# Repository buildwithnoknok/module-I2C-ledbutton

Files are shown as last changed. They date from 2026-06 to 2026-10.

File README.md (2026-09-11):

# noknok LED Button

A compact I²C‑controlled button module with integrated RGB LED backlight for the noknok ecosystem.  
Designed for user input, menu navigation, and illuminated UI feedback in modular builds.

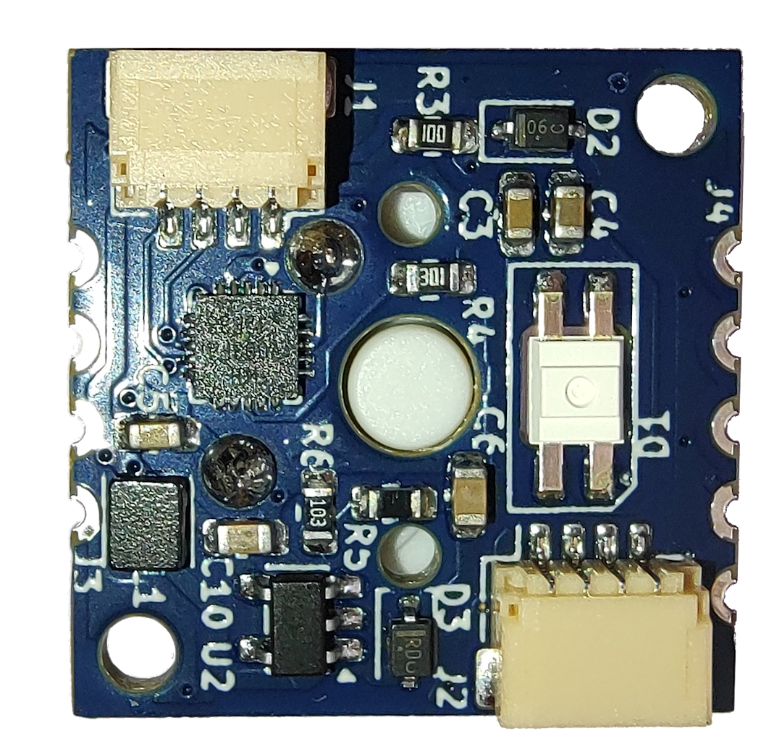
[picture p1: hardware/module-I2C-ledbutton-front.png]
LED Button Module Front

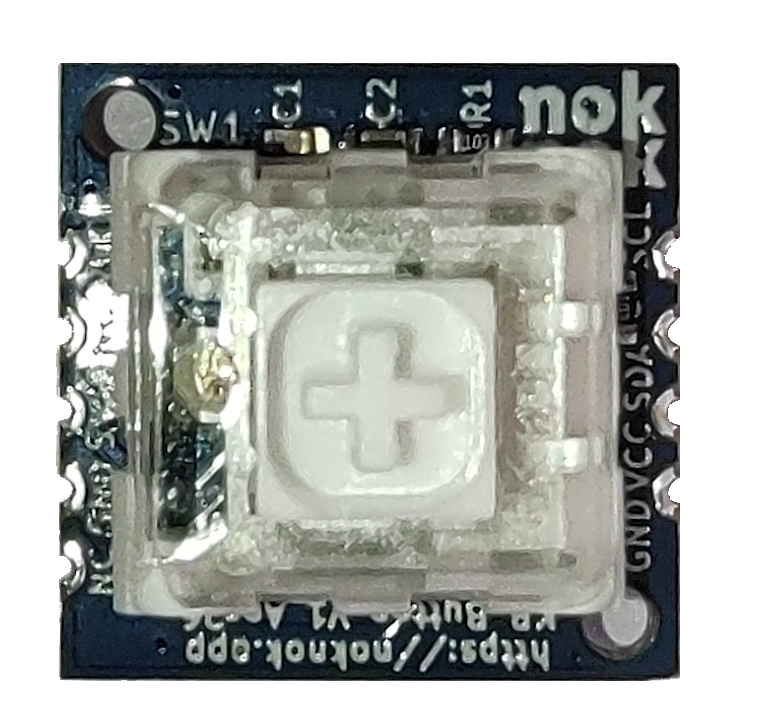
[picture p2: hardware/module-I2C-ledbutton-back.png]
LED Button Module Back


---

## Overview

The **noknok LED Button** uses a **CH32V003F4U6** microcontroller to read a tactile push button and drive an **SK6812MINI-E** RGB LED via SPI+DMA. It connects to the Raspberry Pi Pico (Conductor) over the standard noknok **JST SH 4‑pin I²C connector**.

The I²C address is assigned dynamically at boot — no conflicts when using multiple modules on the same bus.

Typical use cases:
- Menu selection (OK / Back / Cancel)
- Illuminated status indicators
- Multi‑button control panels
- Confirm actions with colour feedback

---

## Features

- Dynamic I²C address via noknok enumeration protocol (no hardcoded address)
- CH32V003F4U6 microcontroller (RISC‑V, 48 MHz, QFN-20)
- SK6812MINI-E RGB LED (SPI + DMA driven — CPU-free updates)
- Tactile push button with 20 ms hardware debounce
- Press edge, release edge, and cumulative press count — no polling gaps
- 3.3V operation via noknok I²C connector
- Compact 20×20 mm PCB

---

## I²C Protocol

**I²C address:** assigned dynamically at boot — see [Enumeration](#enumeration).

### Commands (Pico → Module)

| Bytes | Command | Description |
|---|---|---|
| `0x00` | **LED OFF** | Turn LED off immediately |
| `0x10` `R` `G` `B` `0x00` | **SET COLOR** | Set LED colour (R, G, B each 0–255) |
| `0x11` | **RESET COUNT** | Reset cumulative press counter to 0 |
| `0xB0` | **ENTER BOOTLOADER** | Reset into the I²C bootloader for an over‑the‑wire firmware update (see [Firmware](#firmware)) |
| `0xB1` | **GET VERSION** | Standard noknok command — the next read returns 4 version bytes (see below) |

### Version read (Pico ← Module)

`GET_VERSION` (`0xB1`) is a **noknok ecosystem-standard** command (the `0xB0`–`0xBF` range is reserved for standard commands across every module). Write `0xB1`, then read **4 bytes**: `[PROTOCOL_VERSION, FW_MAJOR, FW_MINOR, FW_PATCH]` = `[0x01, 2, 2, 0]`. Lets the Conductor compare the installed version against the version required by the product manifest. **→ Full spec:** [Ecosystem / software / readme.md §5](https://github.com/buildwithnoknok/Ecosystem/blob/main/software/readme.md#5-standard-system-commands)

### Status read (Pico ← Module)

Read **2 bytes**:

**Byte 0 — status flags:**

| Bit | Meaning |
|-----|---|
| 0 | Button currently pressed (`1` = held down) |
| 1 | Press event since last read (edge, auto-clears) |
| 2 | Release event since last read (edge, auto-clears) |

**Byte 1 — cumulative press count** (0–255, wraps)

> Edge flags (bits 1 and 2) are cleared on the module after each read. Poll at ~50 ms and you won't miss any press or release.

---

## Enumeration

The module uses the standard noknok dynamic enumeration protocol — no hardcoded I²C address. At boot it flashes the LED white briefly, then counts a UID-derived backoff delay before joining the bus at `0x7F` for address assignment. On successful assignment, the LED flashes green.

**→ Full protocol spec:** [Ecosystem / software / enumeration.md](https://github.com/buildwithnoknok/Ecosystem/blob/main/software/enumeration.md)

---

## Python API

Use the `noknok.py` library from the [Ecosystem repo](https://github.com/buildwithnoknok/Ecosystem/tree/main/software/pico) on the Pico.

```python
from noknok import Conductor

c = Conductor()        # GP8 = SDA, GP9 = SCL
c.enumerate()          # discover all modules (~3 s)

kb = c.ledbutton[0]             # first LED Button by discovery order
# or: kb = c.role["ok_button"]  # by role name after setup_roles()

# LED control
kb.set_color(255, 0, 0)         # red
kb.set_color(0, 255, 0)         # green
kb.set_color(255, 255, 255)     # white
kb.led_off()

# Button reading — returns LedButtonStatus or None on I2C error
s = kb.read()
if s is not None:
    print(s.pressed)        # True if held right now
    print(s.press_event)    # True if pressed since last read
    print(s.release_event)  # True if released since last read
    print(s.count)          # cumulative press count (0–255)

# Reset counter
kb.reset_count()
```

---

## Hardware

| Spec | Value |
|---|---|
| PCB size | 20 × 20 mm |
| MCU | CH32V003F4U6 (QFN‑20, RISC‑V, 48 MHz) |
| LED | SK6812MINI-E (RGB, SPI-driven) |
| Button | Tactile switch, active LOW, internal pull-up |
| Connector | JST SH 4‑pin (Qwiic / STEMMA QT compatible) |
| Supply voltage | 3.3V via I²C connector |
| LED data pin | PC6 (SPI1 MOSI, DMA-driven) |
| Button pin | PD4 (active LOW) |
| I²C SDA | PC1 |
| I²C SCL | PC2 |
| Flash header | J3 — 3-pad pogo (GND, SWIO, VCC), noknok M2.5-keyed footprint. SWIO/PD1 also carries the status LED (D4, active LOW). |
| Hardware version | v2.0 |

---

## Firmware

**v2.4 runs under the shared noknok I²C bootloader** ([module-I2C-bootloader](https://github.com/buildwithnoknok/module-I2C-bootloader)), so the module can be re‑flashed **over the I²C bus** — no SWDIO cable needed in the field.

Flash map (16 KB):

| Region | Address | Written by |
|---|---|---|
| Bootloader — stage-0 (1 KB, frozen) + stage-1 (4 KB, OTA-updatable) | `0x0000` | SWD, **once** at manufacture |
| Application (this firmware) | `0x1400` | I²C OTA |
| Metadata (validity marker) | `0x3FC0` | I²C OTA |

The application is linked at the `0x1400` offset (`app.ld`, bootloader layout 2) and reserves the top 16 bytes of RAM for the bootloader handoff cell. Command `0xB0` drops the running module back into the bootloader for an update.

### Build

```bash
cd firmware/src
make build   # compile the offset-linked application -> keyboard_firmware.bin
```

> ch32fun must be installed at `../ch32fun/` relative to `firmware/src/` — see [cnlohr/ch32v003fun](https://github.com/cnlohr/ch32v003fun) for setup.

### Flashing

- **Normal (over I²C):** flash `keyboard_firmware.bin` from the Pico using the noknok flasher (`module_flasher.py` in `brain-Pico`). No cable.
- **First time / blank board:** SWD‑flash the bootloader once (`make flash` in the bootloader repo), then flash this app over I²C.
- **Backup / recovery (SWD):** the 5‑pin SWIO header is the unbrickable backstop — see *Recovery & SWD flashing* in the [bootloader README](https://github.com/buildwithnoknok/module-I2C-bootloader#recovery--swd-flashing).

`make flash` here still does a one‑off SWD flash of the app for bench bring‑up if you need it.

| Metric | Value |
|---|---|
| Firmware version | v2.4.1 (bootloader‑hosted, app base `0x1400`) |
| Application size | 3144 B (of the 10 KB app region) |

---

## Changelog

### Hardware v2.0 — status LED, pogo flash pads, no on-board pull-ups
Status LED on PD1/SWIO, castellated edges replaced with 3-pad pogo flashing pads (J3), on-board I²C pull-ups removed (host-only now). Full change record: [hardware/readme.md](hardware/readme.md#hardware-change-record).

### v2.4.1 — version bump only (firmware-index bring-up)
No functional change. Cut purely to give the new firmware-index OTA path a real installed-vs-current delta to exercise end to end (resolve → bootloader gate → fetch → flash → verify). Identical to v2.4.0 apart from the `GET_VERSION` patch byte. Ships alongside the first [`firmware/index.json`](firmware/index.json), which is how the brain now discovers the current firmware for this module — see [Ecosystem / software / firmware-index.md](https://github.com/buildwithnoknok/Ecosystem/blob/main/software/firmware-index.md).

### v2.4.0 — app base 0x1400 (bootloader layout 2)
Relinked at the `0x1400` flash offset (bootloader **layout 2**: 1 KB stage-0 + 4 KB stage-1 below the app; was `0x1000`). Firmware behaviour unchanged. **Not compatible with the legacy monolithic bootloader or a layout-1 stage-1** — such a module gets stage-0 + stage-1 v1.1.0 over SWD first, then this app over I²C. See [module-I2C-bootloader](https://github.com/buildwithnoknok/module-I2C-bootloader).

### v2.3.0 — watchdog + boot-health handshake (DEV-31)
Runs the independent watchdog (~2 s, kicked every main-loop pass) and writes `0` to `0x200007F8` the moment its I²C address is assigned — the app-health handshake with the stage-1 bootloader. Stage-1 counts watchdog resets and parks the module (error 7, rescued by the Conductor by UID) after three in a row, instead of booting a broken app forever. Contract: [Ecosystem / software / bootloader-update.md §3](https://github.com/buildwithnoknok/Ecosystem/blob/main/software/bootloader-update.md). No protocol or command change.

### v2.2.0 — SK6812 LED driver fix
Replaced the hand-rolled SPI+DMA SK6812 driver with cnlohr's proven
[`ws2812b_dma_spi_led_driver.h`](https://github.com/cnlohr/ch32fun/blob/master/extralibs/ws2812b_dma_spi_led_driver.h)
(ch32fun `extralibs`). The old driver produced a **marginal waveform** that
genuine-but-less-tolerant SK6812 lots misread — one batch showed wrong colours
(a spurious green channel) on ~13 of 20 units. This was **initially misdiagnosed
as bad/counterfeit LEDs; the LEDs are genuine OPSCO** — the fault was our driver.
The library produces a clean, glitch-free waveform. Four concrete differences vs.
the old driver:

- **16-bit SPI** transfers (was 8-bit) — cleaner framing, fewer inter-word gaps
- **`SPI1->HSCR = 1`** high-speed read mode (was not set)
- **`DMA_Priority_VeryHigh`** (was medium) — prevents inter-byte gaps under bus contention
- **`SPI1->DATAR = 0`** to force the data line low before the first frame (kills the start-of-frame glitch)

Still DMA (no bit-bang), so it never blocks the I²C / TIM2 interrupts. Wire order
(G, R, B) and the I²C command set are unchanged, so it's a drop-in OTA update.

### v2.1.0 — bootloader-hosted
Offset-linked at `0x1400` to run under the shared noknok I²C bootloader, enabling
I²C OTA firmware updates. Added the `GET_VERSION` (`0xB1`) standard command.

---

## Status

| Area | Status |
|---|---|
| Hardware | v2.0 complete |
| Firmware | **v2.2 — complete (bootloader‑hosted, I²C OTA bench‑proven)** |
| Python library | **complete** (in [Ecosystem repo](https://github.com/buildwithnoknok/Ecosystem/tree/main/software/pico)) |
| Documentation | **complete** |

---

## License

- Firmware / code: MIT — see [LICENSE](LICENSE).
- Hardware (schematics, PCB layout, fab files): CC BY-SA 4.0 — see [LICENSE-hardware](LICENSE-hardware).

## Trademarks

**noknok** is a registered trademark in Switzerland (Swissreg 1300007033).

Qwiic is a registered trademark of SparkFun Electronics, Inc. STEMMA QT is a
trademark of Adafruit Industries, LLC. Both are named here only to state
connector compatibility - noknok is not affiliated with, endorsed by, or
sponsored by either company.
---

---

## Safety & Liability

noknok hardware is an electronic device and a DIY/maker kit. You assemble, modify, flash, power, and operate it at your own risk, and it is provided as is, without warranty. See the full notice: [License, Safety & Liability](https://buildwithnoknok.github.io/safety-and-license/).

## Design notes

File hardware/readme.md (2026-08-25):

# Hardware — noknok LED Button

Hardware design files for the noknok LED Button module (CH32V003F4U6 — I2C tactile button with RGB LED backlight).

- KiCad project: `kicad/Keyboard_LED_button.*`
- Schematic (PDF): `module-I2C-LEDButton_Schematics.pdf`
- BOM: `module_I2C-LEDButton.xls`
- Board renders: `module-I2C-ledbutton-front.png`, `module-I2C-ledbutton-back.png` *(pre-V2 renders — pending re-export)*

Hardware is licensed CC BY-SA 4.0 (see `../LICENSE-hardware`). Connector, flashing and mounting standards follow the [noknok Ecosystem guidelines](https://github.com/buildwithnoknok/Ecosystem) (electrical + mechanical).

---

## Hardware Change Record

### v2.0 — changes from v1.1
- **Status indicator LED on PD1** (in parallel with the SWIO flashing line — zero extra GPIO). Active-low: `+3V3_PROT → R5 (2.2 kΩ) → D4 anode; D4 cathode → PD1/SWIO`. Driven by the bootloader (off = app running, slow pulse = updating/recovering, solid = error). Parts: red 0603 LED (LCSC C2286) + 2.2 kΩ 0603 (LCSC C4190).
- **Removed the castellated edge pads** — both the I2C edge and the flashing edge (unreliable to contact). I2C is via the JST-SH (Qwiic) connectors J1/J2 only.
- **New flashing interface (J3)** — noknok flash pads (`noknok_FlashPads_I2C-module_1x3_M2.5`): 3 single-side SMD pogo pads (GND / SWIO / VCC) plus an embedded M2.5 keyed mounting hole, from the noknok KiCad library in the Ecosystem repo.
- **Second mounting hole (H1)** — plain `noknok_MountingHole_2.5mm_M2.5`, diagonally opposite the flash-pad hole.
- **Removed the on-board I²C pull-up resistors** (previously R1/R2) — pull-ups now live on the host (Conductor), not per module (avoids stacking on the shared bus). The host must provide the bus pull-ups (proposed 3.3 kΩ); a noknok pull-up PCB covers third-party hosts that lack them. See the [I²C Pull-up Resistor Strategy ADR](https://noknokdev.atlassian.net/wiki/spaces/SD/pages/82280449).
- **Remaining resistors renumbered** after the pull-ups were removed (values unchanged): VDD series R3→**R1** (10 Ω, no spike issue), LED current R4→**R2** (300 Ω), boost feedback divider R5/R6→**R3**/**R4** (25 kΩ / 10 kΩ). New status-LED resistor is **R5** (2.2 kΩ, see above).
- D1 (SK6812MINI-E RGB LED, payload), D2 (protection Zener) and D3 (boost-converter Schottky) are unchanged from v1.1.

**Gap vs. Knob/Buzzer V2 docs:** the board renders are still the pre-V2 photos, pending new production units.

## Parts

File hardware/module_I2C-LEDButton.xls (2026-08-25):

Item # | *Designator | *Qty | Manufacturer | *Mfg Part # | Description / Value | LCSC Part # | *Package/Footprint | Substitute
1 | C1, C4, C7 | 3 | SAMSUNG | CL10A106KP8NNNC | 10uF | C19702 | C_0603_1608Metric
2 | C2, C3, C5 | 3 | SAMSUNG | CL10B104KA8NNNC | 0.1uF | C1590 | C_0603_1608Metric
3 | C6 | 1 | SAMSUNG | CL10A226MP8NUNE | 22uF | C86295 | C_0603_1608Metric
4 | D1 | 1 | OPSCO Optoelectronics | SK6812MINI-E | SK6812MINI-E | C5149201 | LED_SK6812MINI-E_3.2x2.8mm_P1.5mm_ReverseMount
5 | D2 | 1 | onsemi | MM3Z3V6T1G | D_Zener | C116949 | D_SOD-323 | ROHM『 』UDZVTE-173.6B『 』C209558
6 | D3 | 1 | onsemi | NSR0320MW2T1G | D_Schottky | C48192 | D_SOD-323
7 | D4 | 1 | Hubei KENTO Elec | KT-0603R | LED RED WATER CLEAR 0603 SMD | C2286 | 0603
8 | J1, J2 | 2 | JST | SM04B-SRSS-TB(LF)(SN) | JST 4 Pin Qwiic I2C Connector | C160404 | JST_SH_SM04B-SRSS-TB_1x04-1MP_P1.00mm_Horizontal
9 | L1 | 1 | cjiang | FTC252010S4R7MBCA | Inductor 4.7uH | C5832360 | L_Changjiang_FTC252010S
10 | R1 | 1 | YAGEO | RC0603JR-0710RL | 10R | C109317 | R_0603_1608Metric | Viking『 』ARG03FTC0100『 』C217691
11 | R2 | 1 | YAGEO | RC0603JR-07300RL | 300R | C137637 | R_0603_1608Metric | Viking『 』ARG03FTC3000『 』C217952
12 | R3 | 1 | YAGEO | RC0603FR-0725KL | 25k | TBD | R_0603_1608Metric | Viking『 』AR03BTCX2502『 』C2828637
13 | R4 | 1 | YAGEO | RC0603JR-0710KL | 10k | C99198 | R_0603_1608Metric | Viking『 』ARG03FTC1002『 』C217687
14 | R5 | 1 | YAGEO | RC0603JR-072K2L | 2.2k | C113303 | R_0603_1608Metric | Viking『 』ARG03FTC2201『 』C217937
15 | SW1 | 1 | Gateron | KS-7SE10B055NW-Y32 | Gateron North Pole 2.0 Switch - Brown Box | N/A | 5-pin keyboard switch | 2.0 Arctic Brown Switch (5-pin, pack of 10) ( KS-7北极轴茶2.0)- https://gateron.cn/product/detail/444
16 | U1 | 1 | WCH | CH32V003F4U6 | CH32V003F4U6 | C5299908 | QFN-20-1EP_3x3mm_P0.4mm_EP1.65x1.65mm
17 | U2 | 1 | XI'AN Aerosemi Tech | MT3540-F23 | MT3540-F23 | C181783 | SOT-23-5

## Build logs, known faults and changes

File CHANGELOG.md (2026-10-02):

# Changelog - noknok LED Button module firmware

Newest first. One entry per version bump, written in the same commit as the bump. Format:
`## <version> - <date>` then `- DEV-xx - what changed and why. Breaking: yes/no.`
Convention: Confluence "Development Conventions" (SD space, page 120160257).

## Baseline - 2026-10-02

- Changelog starts here. Current: led_button firmware 2.4.1 (released 2026-09-11). Earlier history: git log and the README.

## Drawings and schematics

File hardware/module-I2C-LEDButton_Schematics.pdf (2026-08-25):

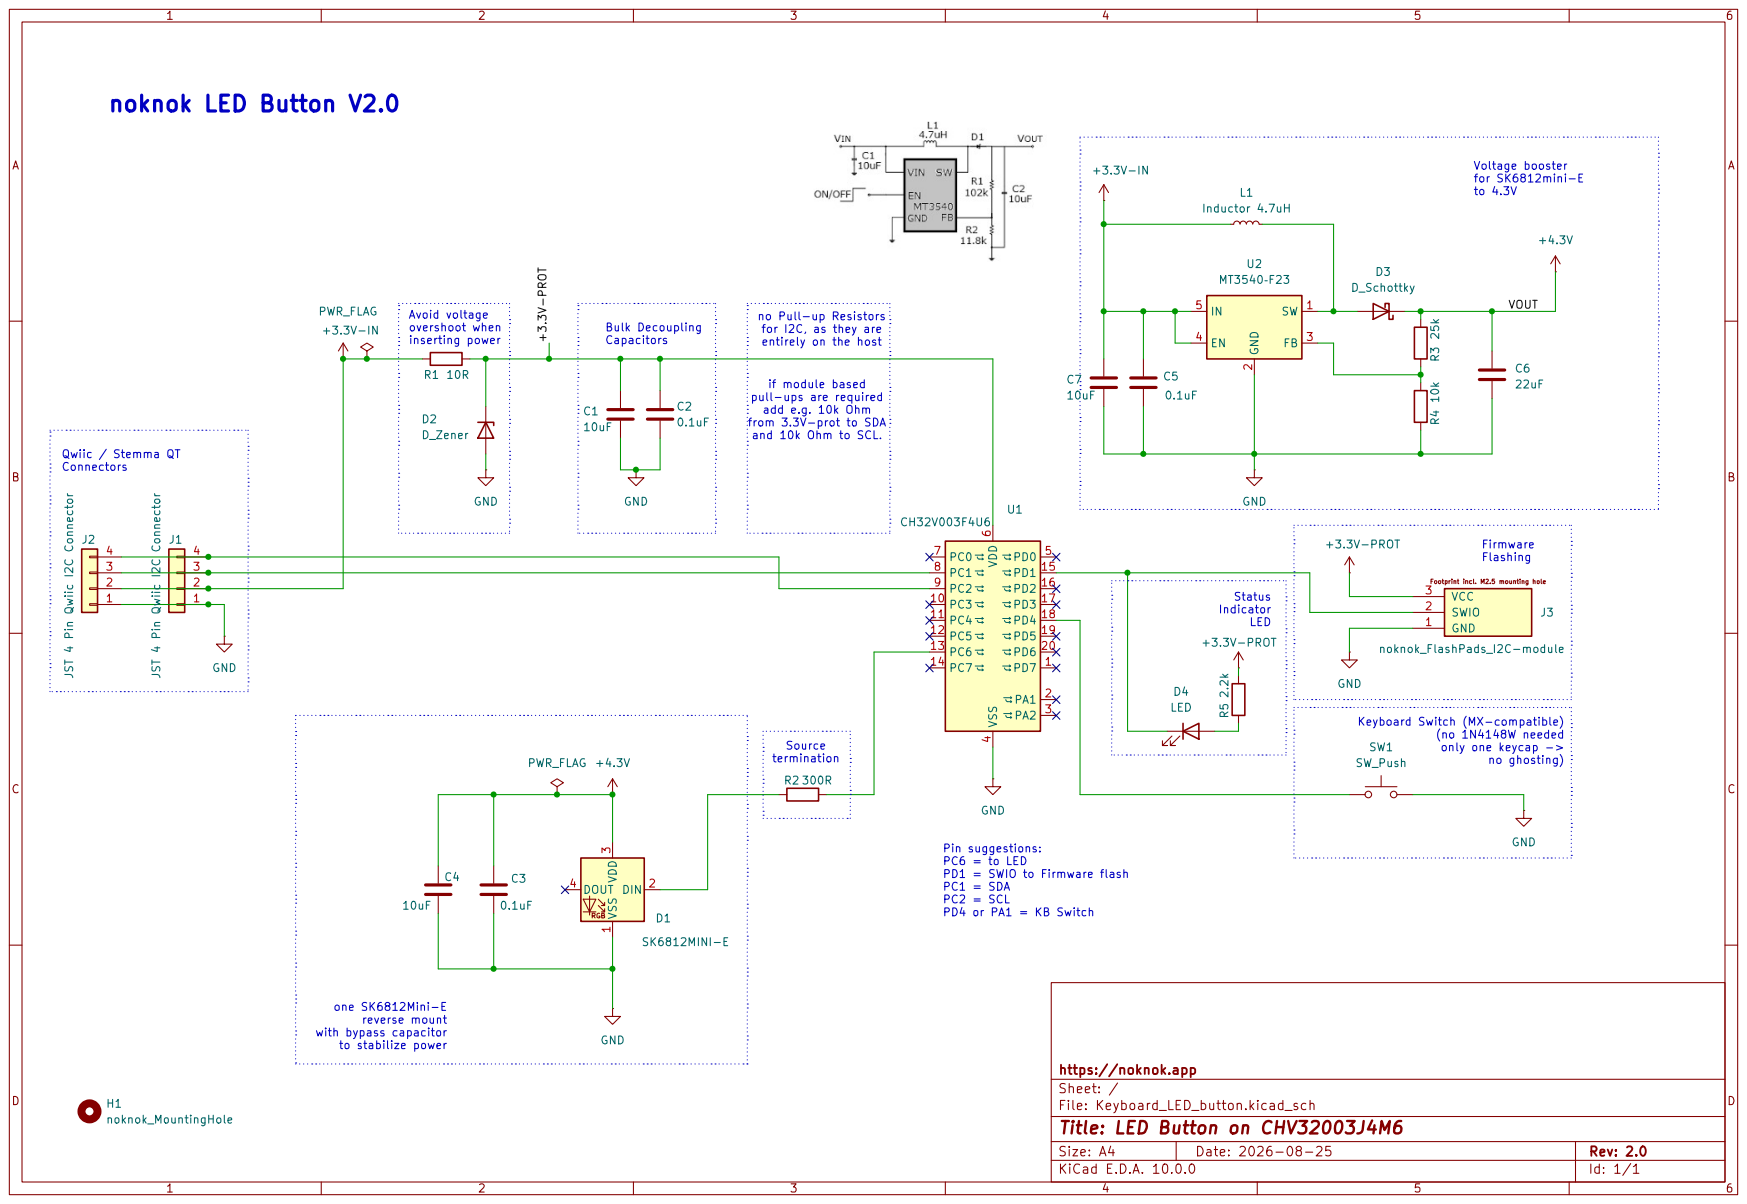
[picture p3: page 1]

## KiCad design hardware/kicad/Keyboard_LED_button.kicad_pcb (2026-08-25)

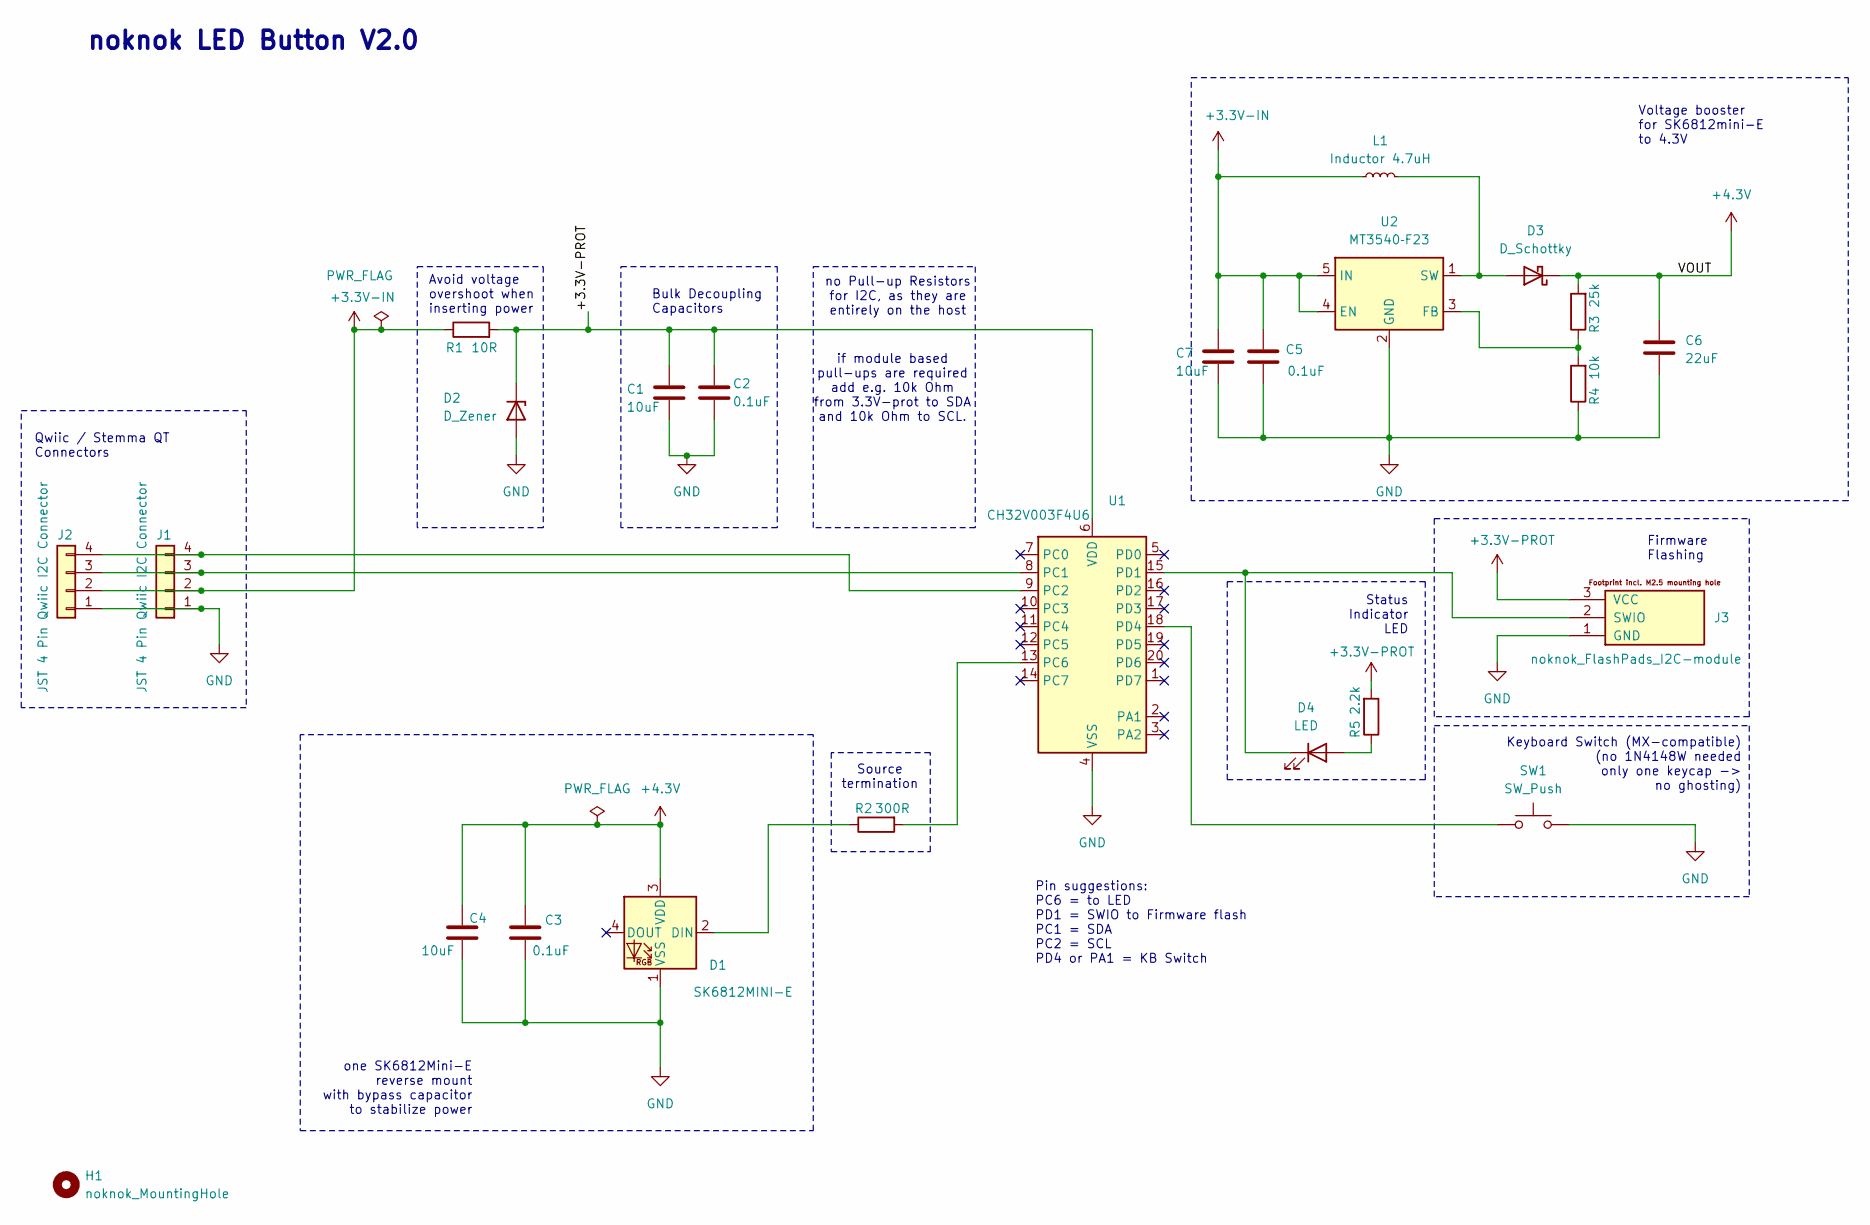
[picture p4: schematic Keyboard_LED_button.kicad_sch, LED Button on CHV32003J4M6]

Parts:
C1, C4, C7: 10uF; C_0603_1608Metric
C2, C3, C5: 0.1uF; C_0603_1608Metric
C6: 22uF; C_0603_1608Metric
D1: SK6812MINI-E; LED_SK6812MINI-E_3.2x2.8mm_P1.5mm_ReverseMount
D2: D_Zener; D_SOD-323
D3: D_Schottky; D_SOD-323
D4: LED; LED_0603_1608Metric
H1: noknok_MountingHole; noknok_MountingHole_2.5mm_M2.5
J1, J2: JST 4 Pin Qwiic I2C Connector; JST_SH_SM04B-SRSS-TB_1x04-1MP_P1.00mm_Horizontal
J3: noknok_FlashPads_I2C-module; noknok_FlashPads_I2C-module_1x3_M2.5
L1: Inductor 4.7uH; L_Changjiang_FTC252010S
R1: 10R; R_0603_1608Metric
R2: 300R; R_0603_1608Metric
R3: 25k; R_0603_1608Metric
R4: 10k; R_0603_1608Metric
R5: 2.2k; R_0603_1608Metric
SW1: SW_Push; SW_Cherry_MX_1.00u_PCB_CHRIS
U1: CH32V003F4U6; QFN-20-1EP_3x3mm_P0.4mm_EP1.65x1.65mm
U2: MT3540‑F23; SOT-23-5

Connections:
+3.3V-IN: C5.1, C7.1, J1.2, J2.2, L1.1, R1.1, U2.4 (EN), U2.5 (IN)
+3.3V-PROT: C1.1, C2.1, D2.1 (K), J3.3 (VCC), R1.2, R5.2, U1.6 (VDD)
+4.3V: C3.1, C4.1, C6.1, D1.3 (VDD), D3.1 (K), R3.2
GND: C1.2, C2.2, C3.2, C4.2, C5.2, C6.2, C7.2, D1.1 (VSS), D2.2 (A), J1.1, J2.1, J3.1 (GND), R4.1, SW1.1, U1.4 (VSS), U1.21 (VSS), U2.2 (GND)
unnamed: D1.2 (DIN), R2.1
unnamed: D3.2 (A), L1.2, U2.1 (SW)
unnamed: D4.2 (A), R5.1
unnamed: D4.1 (K), J3.2 (SWIO), U1.15 (PD1)
unnamed: J1.3, J2.3, U1.8 (PC1)
unnamed: J1.4, J2.4, U1.9 (PC2)
unnamed: R2.2, U1.13 (PC6)
unnamed: SW1.2, U1.18 (PD4)
unnamed: R3.1, R4.2, U2.3 (FB)

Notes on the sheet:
Voltage booster for SK6812mini-E to 4.3V
if module based pull-ups are required add e.g. 10k Ohm from 3.3V-prot to SDA and 10k Ohm to SCL.
Avoid voltage overshoot when inserting power
noknok LED Button V2.0
Pin suggestions: PC6 = to LED PD1 = SWIO to Firmware flash PC1 = SDA PC2 = SCL PD4 or PA1 = KB Switch
no Pull-up Resistors for I2C, as they are entirely on the host
Status Indicator LED
Firmware Flashing
Source termination
Qwiic / Stemma QT Connectors
Bulk Decoupling Capacitors
Keyboard Switch (MX-compatible) (no 1N4148W needed only one keycap -> no ghosting)
one SK6812Mini-E reverse mount with bypass capacitor to stabilize power

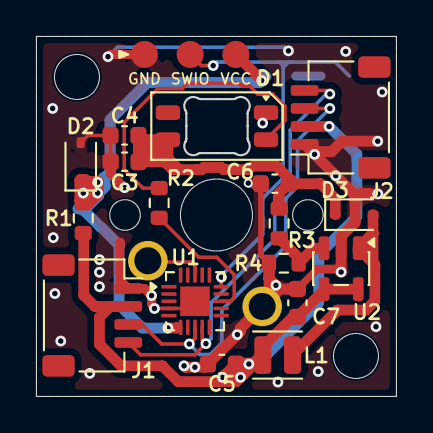
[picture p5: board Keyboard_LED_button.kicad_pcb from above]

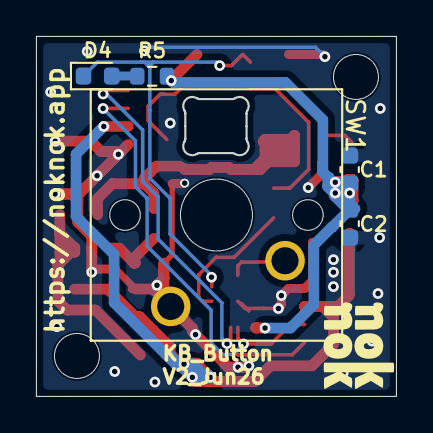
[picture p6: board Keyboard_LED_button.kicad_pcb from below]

Board: 2 copper layers, 20.0 x 20.0 mm, 24 parts (5 on the bottom side), 13 nets.

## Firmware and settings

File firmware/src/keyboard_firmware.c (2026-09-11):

/*
 * noknok Keyboard Button Module Firmware  v2.4.1
 * CH32V003F4U6 (QFN-20)  |  Stack: cnlohr/ch32fun
 *
 * v2.4.1: version bump only — no functional change. Cut to give the
 *   firmware-index OTA path (firmware/index.json) a real installed-vs-current
 *   delta to exercise on the bench. Byte-for-byte identical to v2.4.0 apart
 *   from the GET_VERSION patch byte.
 * v2.4.0: relinked at the 0x1400 flash offset (bootloader layout 2).
 * v2.3: DEV-31 hardening C — independent watchdog + boot-attempt handshake
 *   with stage-1 (clears the counter once an I2C address is assigned).
 * v2.2: LED driver swapped to cnlohr's ch32fun ws2812b_dma_spi_led_driver.h.
 *       The previous hand-rolled SPI/DMA driver produced a marginal waveform
 *       that genuine-but-less-tolerant SK6812 lots misread (wrong colours on
 *       ~13/20 of a batch). The library's clean waveform fixes it — same DMA,
 *       no bit-bang. See the LED section below.
 *
 * ── Bootloader-hosted build (v2.0) ────────────────────────────────────────
 *   This application runs UNDER the shared noknok I2C bootloader
 *   (module-I2C-bootloader). It is linked at the 0x1400 flash offset (app.ld)
 *   and reserves the top 16 bytes of RAM for the bootloader handoff cell at
 *   0x200007F0. Command 0xB0 drops the running module back into the bootloader
 *   so the Pico can re-flash it over I2C — no SWDIO cable. The bootloader is a
 *   separate binary, SWD-flashed once per board; this image is flashed via I2C.
 *
 * ── Hardware ──────────────────────────────────────────────────────────────
 *   PC6  SPI1_MOSI  → SK6812MINI-E LED DIN  (DMA-driven, CPU-free)
 *   PC1  I2C SDA
 *   PC2  I2C SCL
 *   PD4  Button (active-low, internal pull-up)
 *   PD1  SWIO (programming)
 *
 * ── SK6812 LED driver ─────────────────────────────────────────────────────
 *   ch32fun extralibs/ws2812b_dma_spi_led_driver.h (cnlohr) — SPI1 + DMA1-Ch3
 *   on PC6, wire order G,R,B (24 bits). Clean, glitch-free waveform via 16-bit
 *   SPI transfers, HSCR high-speed mode, very-high DMA priority and a line-low
 *   start. DMA (fire-and-forget) — never blocks the I2C / TIM2 interrupts.
 *
 * ── Enumeration ───────────────────────────────────────────────────────────
 *   Staging address : 0x7F
 *   MODULE_TYPE     : 0x03 (keyboard/button)
 *   Response (10 bytes): [UID×8][0x03][CRC8]
 *
 * ── I2C protocol after enumeration ───────────────────────────────────────
 *   Master WRITE:
 *     [0x00]              LED off
 *     [0x10, R, G, B, W]  Set LED colour (0-255 each channel)
 *     [0x11]              Reset cumulative press counter
 *     [0xB0]              Enter bootloader (reset into I2C OTA flash mode)
 *     [0xB1]              Get version — next read returns 4 version bytes
 *   Master READ (2 bytes, default):
 *     Byte 0 – status flags
 *       bit 0  current button state (1 = pressed right now)
 *       bit 1  press edge since last read  (cleared on read)
 *       bit 2  release edge since last read (cleared on read)
 *     Byte 1 – cumulative press count (wraps at 255)
 *   Master READ (4 bytes, after 0xB1):
 *     [PROTOCOL_VER, FW_MAJOR, FW_MINOR, FW_PATCH]
 *
 *   GET_VERSION (0xB1) is a noknok ecosystem-standard command (range
 *   0xB0–0xBF reserved). See Ecosystem/software/readme.md §5.
 */

#include "ch32fun.h"
#include <string.h>
#include <stdint.h>

/* ═══════════════════════════════════════════════════════════════════════════
 * CONFIGURATION
 * ═══════════════════════════════════════════════════════════════════════════ */

#define ENUM_ADDR        0x7F
#define MODULE_TYPE      0x03
#define REG_ASSIGN_ADDR  0x1D

#define CMD_LED_OFF          0x00
#define CMD_LED_SET          0x10
#define CMD_CNT_RESET        0x11
#define CMD_ENTER_BOOTLOADER 0xB0   /* reset into the I2C bootloader for OTA update */
#define CMD_GET_VERSION      0xB1   /* report [PROTOCOL_VERSION, FW_MAJOR, FW_MINOR, FW_PATCH] */

#define UID_ADDR         ((volatile uint8_t*)0x1FFFF7E8)
#define UID_LEN          8

/* ── Version reporting (noknok standard command, DEV-1) ──────────────────────
 * PROTOCOL_VERSION = which noknok protocol/API this module speaks — NOT the
 * firmware version. Bumped only when the shared protocol changes. The
 * FW_VERSION_* triple is this module's firmware semver; keep it equal to the
 * release tag. Reported on a GET_VERSION (0xB1) read. */
#define PROTOCOL_VERSION 0x01
#define FW_VERSION_MAJOR 2
#define FW_VERSION_MINOR 4
#define FW_VERSION_PATCH 1

/* Bootloader handoff cell — top 16 B of RAM, reserved by app.ld (stack ends
 * below it). Writing this magic then warm-resetting drops the module into the
 * shared noknok I2C bootloader, which sees the magic on boot and stays in flash
 * mode at 0x7E. SRAM survives a warm reset, so the magic is still there. Magic
 * and address MUST match noknok_bootloader. */
#define BL_MAGIC_CELL    (*(volatile uint32_t *)0x200007F0U)
#define BL_MAGIC_ENTER   0x6E6B4231U   /* "nkB1" */

/* ── App health handshake with stage-1 (DEV-31 hardening C) ──────────────────
 * Stage-1 counts every boot of this app in a no-init RAM cell and stops booting
 * it after three consecutive warm resets without the app ever proving itself,
 * parking the module in the bootloader at 0x7E so the host can push a good
 * image instead. That turns "a broken app with a valid CRC is booted forever"
 * into "a broken app gets three tries". Two things make it work here:
 *   - the independent watchdog, so a hang becomes a warm reset (~2 s), and
 *   - clearing the counter the moment we KNOW we are healthy: an I2C address
 *     has been assigned, i.e. enumeration completed, i.e. I2C works.
 * Address and tag must match noknok_stage1. */
#define BOOT_ATTEMPT_CELL (*(volatile uint32_t *)0x200007F8U)

static void iwdg_init(void)
{
    /* LSI ~128 kHz / 64 = 2 kHz; reload 4095 -> ~2.05 s. Hardware starts LSI. */
    IWDG->CTLR = 0x5555;  IWDG->PSCR = 4;
    IWDG->CTLR = 0x5555;  IWDG->RLDR = 0xFFF;
    IWDG->CTLR = 0xCCCC;  /* start — cannot be stopped except by reset */
}
static inline void iwdg_kick(void) { IWDG->CTLR = 0xAAAA; }

/* ═══════════════════════════════════════════════════════════════════════════
 * STATE
 * ═══════════════════════════════════════════════════════════════════════════ */

typedef enum {
    DEV_BOOT_WAITING,
    DEV_ENUM_READY,
    DEV_ASSIGNING,
    DEV_ASSIGNED,
} DeviceState;

static volatile DeviceState dev_state = DEV_BOOT_WAITING;
static volatile uint32_t    ms_tick   = 0;
static volatile uint8_t     new_addr  = 0;
static volatile uint8_t     version_pending = 0; /* set in ISR on 0xB1; next read returns version */

/* ─── Button ─────────────────────────────────────────────────────────────── */
static volatile uint8_t btn_state    = 0;   /* 1 = currently pressed */
static volatile uint8_t btn_pressed  = 0;   /* edge flag — cleared on read */
static volatile uint8_t btn_released = 0;   /* edge flag — cleared on read */
static volatile uint8_t btn_count    = 0;   /* cumulative press count       */

/* ─── LED ────────────────────────────────────────────────────────────────── */
static volatile uint8_t  led_r = 0, led_g = 0, led_b = 0, led_w = 0;
static volatile uint8_t  led_update_pending = 0;
static volatile uint32_t flash_off_ms = 0;   /* non-zero while startup flash is active */

/* ─── I2C buffers ────────────────────────────────────────────────────────── */
#define RX_BUF_SIZE 8
#define TX_BUF_SIZE 10

static volatile uint8_t rx_buf[RX_BUF_SIZE];
static volatile uint8_t rx_len    = 0;
static volatile uint8_t cmd_ready = 0;

static volatile uint8_t tx_buf[TX_BUF_SIZE];
static volatile uint8_t tx_len = 0;
static volatile uint8_t tx_idx = 0;


/* ═══════════════════════════════════════════════════════════════════════════
 * CRC8  (polynomial 0x07, init 0x00)
 * ═══════════════════════════════════════════════════════════════════════════ */

static uint8_t crc8(const uint8_t *data, uint8_t len)
{
    uint8_t crc = 0x00;
    for (uint8_t i = 0; i < len; i++) {
        crc ^= data[i];
        for (uint8_t j = 0; j < 8; j++)
            crc = (crc & 0x80) ? (crc << 1) ^ 0x07 : (crc << 1);
    }
    return crc;
}


/* ═══════════════════════════════════════════════════════════════════════════
 * BACKOFF  —  FNV-1a hash of 8-byte UID
 * ═══════════════════════════════════════════════════════════════════════════ */

static uint32_t backoff_ms;
static uint32_t enum_ready_start_ms = 0;

static uint32_t fnv_hash(uint32_t h)
{
    volatile uint8_t *uid = UID_ADDR;
    for (uint8_t i = 0; i < UID_LEN; i++) {
        h ^= uid[i];
        h *= 16777619UL;
    }
    return h;
}

static void calc_backoff(void)
{
    backoff_ms = (fnv_hash(2166136261UL) % 2500) + 300;
}

static uint32_t calc_rebackoff_ms(void)
{
    return ms_tick + (fnv_hash(ms_tick) % 500) + 50;
}


/* ═══════════════════════════════════════════════════════════════════════════
 * UID RESPONSE  —  10 bytes: [UID×8][MODULE_TYPE][CRC8]
 * ═══════════════════════════════════════════════════════════════════════════ */

static void build_uid_response(void)
{
    volatile uint8_t *uid = UID_ADDR;
    for (uint8_t i = 0; i < UID_LEN; i++) tx_buf[i] = uid[i];
    tx_buf[8] = MODULE_TYPE;
    tx_buf[9] = crc8((const uint8_t*)tx_buf, 9);
    tx_len = 10;
    tx_idx = 0;
}

/* 4-byte GET_VERSION response: [PROTOCOL_VERSION, FW_MAJOR, FW_MINOR, FW_PATCH] */
static void build_version_response(void)
{
    tx_buf[0] = PROTOCOL_VERSION;
    tx_buf[1] = FW_VERSION_MAJOR;
    tx_buf[2] = FW_VERSION_MINOR;
    tx_buf[3] = FW_VERSION_PATCH;
    tx_len = 4;
    tx_idx = 0;
}


/* ═══════════════════════════════════════════════════════════════════════════
 * SK6812MINI-E LED  —  cnlohr's proven SPI1 + DMA1-Ch3 driver (PC6 = SPI1_MOSI)
 *
 * Uses ch32fun's extralibs/ws2812b_dma_spi_led_driver.h. This replaced a
 * hand-rolled SPI/DMA driver whose marginal waveform was misread by genuine-
 * but-less-tolerant SK6812 lots (7/20 units tolerated it, 13/20 showed wrong
 * colours). The library produces a clean, glitch-free waveform — 16-bit SPI
 * transfers, HSCR high-speed mode, very-high DMA priority, and a line-low start
 * — so every unit reads it correctly. Still DMA (no bit-bang), so it never
 * blocks the I2C / TIM2 interrupts.
 *
 * Wire order is G, R, B — the driver's default order, streamed MSB-first, so the
 * colour word is packed 0x00GGRRBB. The driver owns DMA1_Channel3_IRQHandler.
 * ═══════════════════════════════════════════════════════════════════════════ */

#define WS2812DMA_IMPLEMENTATION
#define DMALEDS 4                  /* must be divisible by 4; we drive LED 0 only */
#include "ws2812b_dma_spi_led_driver.h"

static volatile uint32_t led_color = 0;   /* 0x00GGRRBB for the single LED */

uint32_t WS2812BLEDCallback(int ledno) { return (ledno == 0) ? led_color : 0; }

static void sk6812_init(void) { WS2812BDMAInit(); }

/* Set the LED colour and kick off the DMA frame. Non-blocking. */
static void sk6812_write(uint8_t r, uint8_t g, uint8_t b)
{
    led_color = ((uint32_t)g << 16) | ((uint32_t)r << 8) | b;
    WS2812BDMAStart(1);
}


/* ═══════════════════════════════════════════════════════════════════════════
 * BUTTON  —  PD4, active-low, internal pull-up, 20 ms debounce
 * ═══════════════════════════════════════════════════════════════════════════ */

static void btn_init(void)
{
    RCC->APB2PCENR |= RCC_APB2Periph_GPIOD;
    GPIOD->CFGLR   &= ~(0xF << (4 * 4));
    GPIOD->CFGLR   |=  (0x8 << (4 * 4));  /* input, pull-up/down enable */
    GPIOD->OUTDR   |=  (1 << 4);           /* select pull-up             */
}

/* Called every 1 ms from TIM2 ISR */
static void btn_update(void)
{
    static uint8_t debounce_state = 1;   /* 1 = released */
    static uint8_t debounce_cnt   = 0;

    uint8_t raw = (GPIOD->INDR >> 4) & 1;  /* 1 = released, 0 = pressed */

    if (raw == debounce_state) {
        debounce_cnt = 0;
    } else {
        if (++debounce_cnt >= 20) {          /* 20 × 1 ms = 20 ms stable */
            debounce_state = raw;
            debounce_cnt   = 0;
            if (raw == 0) {                  /* falling edge → press     */
                btn_state   = 1;
                btn_pressed = 1;
                if (btn_count < 255) btn_count++;
            } else {                         /* rising edge → release    */
                btn_state    = 0;
                btn_released = 1;
            }
        }
    }
}


/* ═══════════════════════════════════════════════════════════════════════════
 * TIM2  —  1 ms tick (identical config to buzzer firmware)
 * ═══════════════════════════════════════════════════════════════════════════ */

static void tim2_init(void)
{
    RCC->APB1PCENR  |= RCC_APB1Periph_TIM2;
    TIM2->PSC        = 47;
    TIM2->ATRLR      = 999;
    TIM2->DMAINTENR  = TIM_IT_Update;
    TIM2->SWEVGR     = TIM_UG;
    TIM2->CTLR1     |= TIM_CEN;
    NVIC_EnableIRQ(TIM2_IRQn);
}

void TIM2_IRQHandler(void) __attribute__((interrupt));
void TIM2_IRQHandler(void)
{
    TIM2->INTFR = 0;
    ms_tick++;
    btn_update();   /* accurate 1 ms debounce cadence */
}


/* ═══════════════════════════════════════════════════════════════════════════
 * I2C SLAVE  —  identical init to buzzer firmware (APB1 = 48 MHz)
 * ═══════════════════════════════════════════════════════════════════════════ */

static void i2c_slave_init(uint8_t addr)
{
    RCC->APB2PCENR |= RCC_APB2Periph_GPIOC;
    RCC->APB1PCENR |= RCC_APB1Periph_I2C1;

    /* PC1 = SDA, PC2 = SCL: open-drain AF */
    GPIOC->CFGLR &= ~(0xF << (1 * 4)); GPIOC->CFGLR |= (0xF << (1 * 4));
    GPIOC->CFGLR &= ~(0xF << (2 * 4)); GPIOC->CFGLR |= (0xF << (2 * 4));

    I2C1->CTLR1 |=  I2C_CTLR1_SWRST;
    I2C1->CTLR1 &= ~I2C_CTLR1_SWRST;

    I2C1->CTLR2  = 48;    /* APB1 = 48 MHz */
    I2C1->CKCFGR = 240;   /* 100 kHz standard mode */
    I2C1->OADDR1 = ((uint16_t)addr << 1);

    I2C1->CTLR2 |= I2C_CTLR2_ITEVTEN | I2C_CTLR2_ITBUFEN | I2C_CTLR2_ITERREN;
    I2C1->CTLR1 |= I2C_CTLR1_ACK | I2C_CTLR1_PE;

    NVIC_EnableIRQ(I2C1_EV_IRQn);
    NVIC_EnableIRQ(I2C1_ER_IRQn);
}

static void i2c_switch_addr(uint8_t addr)
{
    I2C1->CTLR1 &= ~I2C_CTLR1_PE;
    I2C1->OADDR1 = ((uint16_t)addr << 1);
    I2C1->CTLR1 |= I2C_CTLR1_ACK | I2C_CTLR1_PE;
}


/* ═══════════════════════════════════════════════════════════════════════════
 * I2C EVENT ISR
 * ═══════════════════════════════════════════════════════════════════════════ */

void I2C1_EV_IRQHandler(void) __attribute__((interrupt));
void I2C1_EV_IRQHandler(void)
{
    uint32_t star1 = I2C1->STAR1;
    uint32_t star2 = I2C1->STAR2;   /* reading STAR2 clears ADDR flag */

    /* ── Address matched ──────────────────────────────────────── */
    if (star1 & I2C_STAR1_ADDR) {
        rx_len = 0;
        I2C1->CTLR1 |= I2C_CTLR1_ACK;

        if (star2 & I2C_STAR2_TRA) {
            /* Master is reading — load first byte immediately */
            if (dev_state == DEV_ENUM_READY) {
                build_uid_response();
                I2C1->DATAR = tx_buf[tx_idx++];
            } else if (version_pending) {
                /* Previous write was GET_VERSION → return the 4 version bytes */
                version_pending = 0;
                build_version_response();
                I2C1->DATAR = tx_buf[tx_idx++];
            } else {
                /* Byte 0: status flags.  Byte 1: press count. */
                tx_buf[0] = (uint8_t)(btn_state
                           | (btn_pressed  << 1)
                           | (btn_released << 2));
                tx_buf[1] = btn_count;
                tx_len = 2; tx_idx = 1;
                btn_pressed  = 0;   /* edge flags cleared on read */
                btn_released = 0;
                I2C1->DATAR = tx_buf[0];
            }
        }
        return;
    }

    /* ── Byte received ────────────────────────────────────────── */
    if (star1 & I2C_STAR1_RXNE) {
        uint8_t b = (uint8_t)I2C1->DATAR;
        if (rx_len < RX_BUF_SIZE) rx_buf[rx_len++] = b;
        return;
    }

    /* ── Transmit buffer empty ────────────────────────────────── */
    if (star1 & I2C_STAR1_TXE) {
        I2C1->DATAR = (tx_idx < tx_len) ? tx_buf[tx_idx++] : 0x00;
        return;
    }

    /* ── Stop condition ───────────────────────────────────────── */
    if (star1 & I2C_STAR1_STOPF) {
        I2C1->CTLR1 |= I2C_CTLR1_PE;   /* clears STOPF */

        if (dev_state == DEV_ENUM_READY) {
            if (rx_len == 2 && rx_buf[0] == REG_ASSIGN_ADDR) {
                new_addr  = rx_buf[1];
                dev_state = DEV_ASSIGNING;
            }
        } else if (dev_state == DEV_ASSIGNED) {
            /* GET_VERSION is handled entirely in the ISR: latch it so the next
             * read returns the version bytes. Don't route it to the main loop. */
            if (rx_len == 1 && rx_buf[0] == CMD_GET_VERSION)
                version_pending = 1;
            else if (rx_len > 0)
                cmd_ready = 1;
        }

        I2C1->CTLR1 |= I2C_CTLR1_ACK;
        return;
    }
}

void I2C1_ER_IRQHandler(void) __attribute__((interrupt));
void I2C1_ER_IRQHandler(void)
{
    I2C1->STAR1 &= ~(I2C_STAR1_BERR | I2C_STAR1_ARLO |
                     I2C_STAR1_AF   | I2C_STAR1_OVR);
    I2C1->CTLR1 |= I2C_CTLR1_ACK;
}


/* ═══════════════════════════════════════════════════════════════════════════
 * COMMAND PROCESSOR
 * ═══════════════════════════════════════════════════════════════════════════ */

static void process_command(void)
{
    if (rx_len < 1) return;

    switch (rx_buf[0]) {
    case CMD_LED_OFF:
        led_r = led_g = led_b = led_w = 0;
        led_update_pending = 1;
        break;

    case CMD_LED_SET:
        if (rx_len >= 5) {
            led_r = rx_buf[1];
            led_g = rx_buf[2];
            led_b = rx_buf[3];
            led_w = rx_buf[4];
            led_update_pending = 1;
        }
        break;

    case CMD_CNT_RESET:
        btn_count = 0;
        break;

    case CMD_ENTER_BOOTLOADER:
        /* Over-the-wire firmware update requested by the Pico. Arm the handoff
         * magic in no-init RAM and warm-reset; the bootloader takes over at 0x7E.
         * NVIC_SystemReset() does not clear SRAM, so the magic survives. */
        BL_MAGIC_CELL = BL_MAGIC_ENTER;
        NVIC_SystemReset();
        break;   /* not reached */

    default:
        break;
    }
}


/* ═══════════════════════════════════════════════════════════════════════════
 * MAIN
 * ═══════════════════════════════════════════════════════════════════════════ */

int main(void)
{
    SystemInit();
    iwdg_init();          /* hardening C: hang -> warm reset -> stage-1 counts it */
    sk6812_init();
    btn_init();
    tim2_init();
    calc_backoff();

    __enable_irq();

    /* Startup: brief white flash — module is alive, I2C still off */
    sk6812_write(20, 20, 20);
    while (WS2812BLEDInUse);
    Delay_Ms(200);
    sk6812_write(0, 0, 0);

    while (1)
    {
        uint32_t now = ms_tick;
        iwdg_kick();          /* every loop iteration; nothing here blocks > 2 s */

        /* ── Enumeration state machine ─────────────────────────── */

        if (dev_state == DEV_BOOT_WAITING && now >= backoff_ms)
        {
            enum_ready_start_ms = now;
            i2c_slave_init(ENUM_ADDR);
            dev_state = DEV_ENUM_READY;
        }

        /* Safety net: re-backoff if not assigned within 200 ms */
        if (dev_state == DEV_ENUM_READY && (now - enum_ready_start_ms) > 200)
        {
            I2C1->CTLR1 &= ~I2C_CTLR1_PE;
            backoff_ms  = calc_rebackoff_ms();
            dev_state   = DEV_BOOT_WAITING;
        }

        if (dev_state == DEV_ASSIGNING)
        {
            i2c_switch_addr(new_addr);
            dev_state = DEV_ASSIGNED;
            BOOT_ATTEMPT_CELL = 0;   /* healthy: I2C works, enumeration done */
            /* Green flash: address successfully assigned.
             * flash_off_ms schedules the turn-off 400 ms later in the main loop. */
            sk6812_write(0, 30, 0);
            flash_off_ms = ms_tick + 400;
        }

        /* ── Normal operation ──────────────────────────────────── */

        if (dev_state == DEV_ASSIGNED)
        {
            if (cmd_ready) {
                cmd_ready = 0;
                process_command();
            }

            /* Turn off startup flash after 400 ms */
            if (flash_off_ms && now >= flash_off_ms && !WS2812BLEDInUse) {
                flash_off_ms = 0;
                sk6812_write(0, 0, 0);
            }

            if (led_update_pending && !WS2812BLEDInUse && !flash_off_ms) {
                led_update_pending = 0;
                sk6812_write(led_r, led_g, led_b);
            }
        }
    }
}

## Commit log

2026-05-08 add schematics
2026-05-08 Create hardware/kicad folder
2026-05-08 Upload Kicad project files
    [Keyboard_LED_button.kicad_pcb, Keyboard_LED_button.kicad_sch]
2026-06-01 Update product name to # noknok LED Button
2026-06-01 firmware: add keyboard button module firmware v1.0
    - CH32V003F4U6 (QFN-20)
    - SK6812MINI-E RGB LED via SPI+DMA (PC6=SPI1_MOSI, 3MHz, GRB only)
    - Button on PD4 with 20ms debounce
    - noknok enumeration protocol v3.1 (MODULE_TYPE=0x03)
    - I2C protocol: set LED colour, read button state + press count
2026-06-01 docs: full README rewrite - correct MCU, LED, protocol, enumeration, Python API, firmware status
2026-06-09 Firmware v2.0: bootloader-hosted build (I2C OTA)
    - Relink application at 0x1000 via app.ld (FLASH 0x1000/len 0x2C00,
    RAM 2032B so the bootloader handoff cell @0x200007F0 is protected)
    - Add 0xB0 ENTER_BOOTLOADER command: write magic 0x6E6B4231 to the
    handoff cell + NVIC_SystemReset() -> drops into the I2C bootloader
    - Makefile: LINKER_SCRIPT := app.ld, default target = build
    - All module logic (enumeration, SK6812 SPI+DMA, button, I2C) unchanged
    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
2026-06-09 Add released firmware binary to firmware/bin
    Track the distributable offset-linked app image (flashed over I2C by the
    Pico). Adds a .gitignore exception so firmware/bin/*.bin is versioned while
    build artifacts elsewhere stay ignored.
2026-06-15 hardware: add hardware/readme.md with v2.0 change record
    v2.0 changes from v1.1: status LED on PD1, optional custom-button thru-holes,
    removed castellated edges, noknok M2.5 mounting holes + flashing pads. (Pull-up change
    deferred pending host-side decision.)
2026-06-15 hardware: v2.0 removes on-board I2C pull-ups (moved to host per pull-up ADR)
2026-06-16 hardware: drop custom-button thru-holes from v2.0 record (did not fit V2; tracked as DEV-10)
2026-06-16 LED Button V2 hardware: updated KiCad schematic + PCB; add V2 + V1.1 schematic PDFs
    Updated Keyboard_LED_button KiCad project (schematic + board) for v2.0; added
    Schematics_LEDButton_V2_20260616.pdf and renamed-as Schematics_LEDButton_V1_1_20260408.pdf;
    removed obsolete Schematics_Keyboard_Button_20260408.pdf and .keep placeholders.
    [Keyboard_LED_button.kicad_pcb, Keyboard_LED_button.kicad_sch]
2026-07-05 mechanical: add housing.json (housing profile v1 scaffold)
    Button opening over SK6812 RGB; clearance heights + position TODO.
2026-07-06 mechanical: LED button housing profile from production files
    Board 20x20; JST J1/J2 identical to buzzer/knob -> template reuses. Payload =
    Cherry MX switch (11.6 mm tall) + SK6812 backlight. top_feature=button 14x14.
    clearance_top=11.6. To confirm: switch centre (inferred 10,10 from LED slot) and
    mounting style (simple opening vs keyboard-plate clip-in).
2026-07-06 mechanical: confirm LED button (centre 10,10, simple opening)
    Christopher confirmed the switch is centred at (10,10) and chose the simple
    opening (cover above the switch) over the plate clip-in. top_feature verified.
2026-07-09 housing.json: cover at PCB level (clearance_top 11.6->0), opening 14x14->16.4x16.2
    Whole switch pokes through at PCB level; opening clears the 15.9x15.7 body, not the
    14x14 plate-notch (Christopher correction).
2026-07-09 housing.json: LED button has 2 diagonal M2.5 holes (not 1)
    Christopher confirmed the board has the standard 2 diagonal M2.5 mounting holes
    (2.25,17.75)+(17.75,2.25), same as the other 20x20 modules -> 2-point column retention.
2026-07-09 housing.json: M2.5 holes to buzzer-standard diagonal (opposite sockets)
2026-07-17 LED Button v2.2: fix SK6812 driver (marginal waveform caused wrong colours)
    Replace the hand-rolled SPI/DMA SK6812 driver with cnlohr's proven ch32fun
    ws2812b_dma_spi_led_driver.h. The old driver produced a marginal waveform that
    genuine-but-less-tolerant SK6812 lots misread (wrong colours / green tint on
    ~13 of 20 units, initially misdiagnosed as bad LEDs). The library's clean
    waveform (16-bit SPI, HSCR high-speed mode, very-high DMA priority, line-low
    start) fixes it, still via DMA (no bit-bang, never blocks I2C/TIM2).
    Validated end-to-end: colours + enumeration + button on previously-corrupt units.
    [keyboard_firmware.c]
2026-07-17 README: v2.2 changelog (SK6812 driver fix + the 4 driver config changes)
2026-07-21 LED Button docs: fix stale V1 references, verify V2 designators against schematic
    - hardware/readme.md pointed at a schematic filename that doesn't exist
    (Schematics_Keyboard_Button_20260408.pdf) - fixed to the actual V2 PDF
    - Added verified designators for the V2 change record (D4/R5 status LED,
    R1-R4 renumbering after pull-up removal) - previously undocumented
    - README.md hardware table still said "Flash header J4 - 5-pin" (the old
    castellated connector) and "Hardware v1.0" - both stale since the V2
    respin in June; fixed to match the shipped J3 pogo-pad interface and v2.0
    - Added a hardware-v2.0 changelog entry (README only had firmware entries)
    - Flagged real gaps vs. knob/buzzer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
2026-07-21 LED Button: add BOM, close the doc gap vs knob/buzzer
    [module_I2C-LEDButton.xls]
2026-08-25 hardware: update KiCad layout and schematic, consolidate schematic PDF and fix readme link
    [Keyboard_LED_button.kicad_pcb, Keyboard_LED_button.kicad_sch, module_I2C-LEDButton.xls]
2026-09-01 README: add trademark attribution for Qwiic and STEMMA QT
    The marks were already used adjectivally to state connector
    compatibility, which is permitted referential use - this adds the
    attribution and an explicit non-affiliation line, and corrects the
    capitalisation of STEMMA QT (Adafruit writes it uppercase).
2026-09-11 v2.3: DEV-31 hardening C - independent watchdog + boot-attempt handshake with stage-1
    Stage-1 now counts every boot of this app and stops booting it after three
    consecutive warm resets without the app proving itself, parking the module in
    the bootloader instead so the host can push a good image. This app's half:
    - IWDG started right after SystemInit (~2 s: LSI/64, reload 4095), kicked
    once per main-loop iteration. A hang becomes a warm reset that stage-1
    counts. Nothing in the loop blocks anywhere near 2 s.
    - BOOT_ATTEMPT_CELL (0x200007F8) cleared on DEV_ASSIGNING -> DEV_ASSIGNED,
    i.e. the moment an I2C address is assigned: enumeration completed, so I2C
    demonstrably work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
    [keyboard_firmware.c]
2026-09-11 v2.4.0: relink at 0x1400 (bootloader layout 2, stage-1 grows to 4 KB)
    No behaviour change. Built on the Pi from this source; the .bin is the layout-2 image. Not compatible with the legacy monolithic bootloader or a layout-1 stage-1 (DEV-31).
    [keyboard_firmware.c]
2026-09-11 v2.4.1 + firmware/index.json (current-firmware index)
    index.json declares the current firmware for this module in the same commit
    as the binary, so the version and the bytes cannot drift apart. Product
    manifests now carry only a floor (min); the brain reads this file to decide
    what to install, and requires_bootloader (stage1 here - app base 0x1400)
    tells it when an image is NOT installable on the module in front of it.
    v2.4.1 is a version bump only, no functional change: FW_VERSION_PATCH 0 -> 1,
    so the binary differs from v2.4.0 by the GET_VERSION patch byte alone. Its
    purpose is to give the new index path a real installed-vs-current delta to
    chase on the bench, end to end (resolve -> bootl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
    [keyboard_firmware.c]
2026-10-04 housing.json: print-tuned values from the 2026-10-03 housing print (see notes)
